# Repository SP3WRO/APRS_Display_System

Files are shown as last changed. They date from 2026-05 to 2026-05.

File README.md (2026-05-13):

# APRS_Display_System
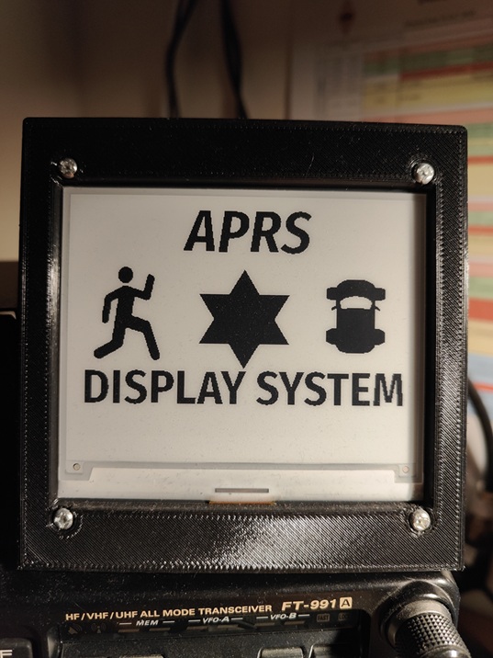
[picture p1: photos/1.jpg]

This is an advanced, multi-functional APRS (Automatic Packet Reporting System) frame display based on the ESP32-WROOM microcontroller. It is used to receive, decode, and display radio (or internet) frames on a low-power e-ink (WeAct 4,2'' BW) screen.

## Programming Description
* The SP3WRO_APRS_DISPLAY.ino and icons.h files should be located together in one folder.
Run the .ino file in the Arduino IDE. In the tools menu, select the HUGE APP (3MB No OTA/1MB SPIFFS) option, as shown in the image.
Then compile the program and upload it to the device. After a moment, the welcome screen will launch.
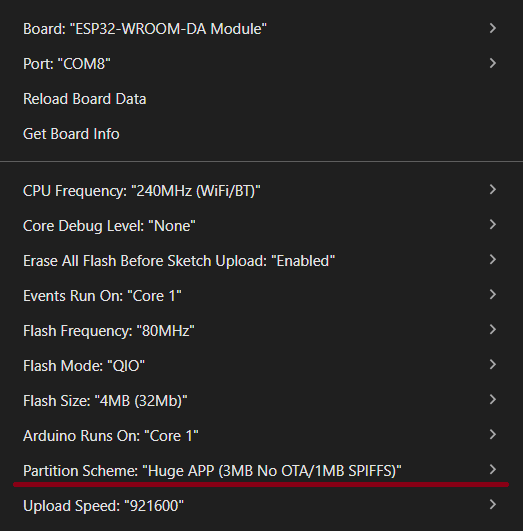
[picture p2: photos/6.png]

## **Four Operating Modes (Data Interfaces):**

- VP-Digi UART (Hardware TNC): The program receives data directly via the physical RX/TX pins from an external modem (e.g., VP-Digi) using the KISS protocol.

* KISS TCP: The ESP32 connects via Wi-Fi as a client to an external KISS TCP server (e.g., DireWolf running on a Raspberry Pi).
* APRS-IS: The ESP32 connects to the global APRS-IS network (e.g., poland.aprs2.net) via WiFi, authenticates with your username and password (passcode), and collects traffic from the surrounding area.
* Bluetooth SPP (HC-05 Client): The ESP32 uses its built-in Bluetooth module to wirelessly connect to an external modem equipped with an HC-05 module (e.g., a mobile tracker or radio).

## **Mechanisms:**
* BT Auto-Fallback (Failover Access Point): If the ESP32 fails to connect to the HC-05 module three times in a row in Bluetooth mode (e.g., radio off, power failure), the program automatically stops attempts, safely resets, and starts its own WiFi network (AP: APRS_DISPLAY_SETUP, IP: 192.168.4.1). This ensures you never lose access to the configuration panel in the event of a modem failure.

## **Data Decoding and Processing (Parser):**
* The program has a powerful internal decoder. It can parse the pure AX.25 protocol wrapped in KISS frames.

## **Supported Formats:**

* Standard position frames, compressed Mic-E format, Base91, weather (WX), and station information (PHG).

## **Radio Identification:**

* The system can recognize the radio model from which the packet was sent (e.g., Yaesu FTM-400, FTM-300, Kenwood TH-D74, APRSdroid app, etc.) based on the comment or destination callsign (TOCALL).

## **Navigational Mathematics:**

* The program continuously calculates the distance (in kilometers) and azimuth (direction, e.g., NW, SE) from your fixed location to the received object.

## **Screen Logic and Display (E-Ink 4.2"):**
* **Classic Mode:**
Displays a large icon of the last received station, an icon (e.g., car, stick figure, home station), a compass rose indicating the direction to the station, raw/decoded data, and the two previous stations in the history.
* **List Mode:**
A more compact layout that displays up to 6 recent stations one below the other, along with a shortened distance, direction, and radio model.
* **EMCOM:** Packets with the EMERGENCY flag bypass filters, activate a visual alarm at the bottom of the screen, trigger an immediate display refresh, and prevent the message from disappearing for one minute.

## **Filters and Additional Features:**
* **Anti-Duplicate:** The program ignores identical packets from the same station for 10 seconds (rejects retransmissions from Digipeaters).
* **Distance Filter:** Ability to reject stations located further than a specified distance.
* **Built-in Web Server:** A complete graphical interface accessible via a browser. It allows you to change all options, enter passwords, change the display mode, and includes a live view of the "Terminal," which receives raw data and device logs.
* **Beacon:** Option to automatically send your own position (frame) to the air (via UART/BT/TCP) or to the network (APRS-IS) at specified intervals.
* **Icons:** The device recognizes the most commonly used icons and displays them in the upper right corner of the screen.

## **Hardware Connection Diagram (Pinout)**
The E-Ink screen uses an SPI bus, while the TNC requires a hardware serial port (UART2). Below is a detailed table showing how to connect the cables between the modules and the ESP32 board (WROOM-32 / DevKit) and an E-Ink display (e.g., Waveshare / GxEPD2 4.2"). Note that the ESP32 has hardware pins assigned for SPI (SCK and MOSI), and the remaining control pins are defined manually in the code.
||||
|--|--|--|
**Pin on E-Ink module** | **Pin on ESP32** | **Description (Function)** |
|VCC | 3.3V | Power supply for the display logic (Never 5V!)|
|GND | GND | Common ground|
|SDA | GPIO 23 | Sending data from ESP to the display (Hardware SPI)|
|SCL | GPIO 18 | Bus clock (Hardware SPI)|
|CS  | GPIO 5 | Defined in code as EPD_CS|
|DC | GPIO 17 | Defined in code as EPD_DC|
|RES | GPIO 16 | Defined in code as EPD_RST|
|BUSY | GPIO 4 | Defined in code as EPD_BUSY|

## Hardware Modem (VP-Digi / TNC) ↔ ESP32 (UART Mode)
The connection uses the hardware serial port on the ESP32. It requires a crossover connection (TX to RX).

||||
|--|--|--|
**Modem pin (e.g., VP-Digi)** | **ESP32 pin** |**Description (Function)**
TX (Transmit from TNC) | GPIO 26 | Defined as VP_RX_PIN (ESP32 receives data)
RX (Receive on TNC) | GPIO 27 | Defined as VP_TX_PIN (ESP32 sends beacon)
GND (Ground) | GND | Common ground between the chips is absolutely critical!

## **Bluetooth module (HC-05 connected to radio)**
* You connect the HC-05 to your mobile modem/radio via hardware using RX/TX cables (e.g., to the DATA port). * The ESP32 board communicates fully wirelessly with this HC-05 via Bluetooth and the MAC address entered in the web configuration panel.
* **Note: WiFi is disabled when using Bluetooth mode!**
## Info
* Software: Mateusz SP3WRO czysty61@gmail.com
* Case: Patryk patrykst1999@o2.pl

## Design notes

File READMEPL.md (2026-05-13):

# APRS_Display_System
Welcome display
To zaawansowany, wielofunkcyjny wyświetlacz ramek APRS (Automatic Packet Reporting System) oparty na mikrokontrolerze ESP32-WROOM, który służy do odbierania, dekodowania i wyświetlania ramek radiowych (lub internetowych) na energooszczędnym ekranie e-ink (WeAct 4,2" BW).

## Opis programowania
Pliki SP3WRO_APRS_DISPLAY.ino oraz icons.h powinny znajdować się razem w jednym folderze.
Uruchamiamy plik .ino w Arduino IDE. W narzędziach wybieramy opcję HUGE APP (3MB No OTA/1MB SPIFFS) tak jak na zdjęciu.
Następnie kompilujemy program i wgrywamy na urządzenie. Po chwili uruchomi się ekran powitalny.
Welcome display
## **Cztery tryby pracy (Złącza danych):**

- VP-Digi UART (Sprzętowy TNC): Program odbiera dane bezpośrednio przez fizyczne piny RX/TX z zewnętrznego modemu (np. VP-Digi) używając protokołu KISS.

* KISS TCP: ESP32 łączy się przez WiFi jako klient z zewnętrznym serwerem KISS TCP (np. z programem DireWolf działającym na Raspberry Pi).
* APRS-IS: ESP32 łączy się przez internet za pomocą WiFi z globalną siecią APRS-IS (np. poland.aprs2.net), autoryzuje się Twoim znakiem i hasłem (passcode) i pobiera ruch z okolicy.
* Bluetooth SPP (Klient HC-05): ESP32 wykorzystuje swój wbudowany moduł Bluetooth, aby bezprzewodowo połączyć się z zewnętrznym modemem wyposażonym w moduł HC-05 (np. z mobilnym trackerem czy radiem).

## **Mechanizmy:**
* BT Auto-Fallback (Awaryjny Punkt Dostępu): Jeśli ESP32 w trybie Bluetooth nie zdoła połączyć się z modułem HC-05 trzy razy z rzędu (np. wyłączone radio, awaria zasilania), program automatycznie wstrzymuje próby, resetuje się w bezpieczny sposób i uruchamia własną sieć WiFi (AP: APRS_DISPLAY_SETUP, IP: 192.168.4.1). Dzięki temu nigdy nie tracisz dostępu do panelu konfiguracyjnego w razie awarii modemu.

## **Dekodowanie i Przetwarzanie Danych (Parser):**
* Program posiada potężny wewnętrzny dekoder. Potrafi analizować czysty protokół AX.25 zawinięty w ramki KISS.
  
## **Obsługiwane formaty:** 

* Standardowe ramki pozycyjne, format skompresowany Mic-E, Base91, pogodowe (WX) oraz informacje o stacji (PHG).
  
## **Identyfikacja Radia:**
  
* System potrafi rozpoznać, z jakiego modelu radia został wysłany pakiet (np. Yaesu FTM-400, FTM-300, Kenwood TH-D74, aplikacja APRSdroid itp.) na podstawie komentarza lub znaków docelowych (TOCALL).

## **Matematyka nawigacyjna:**

* Program na bieżąco oblicza dystans (w kilometrach) oraz azymut (kierunek, np. NW, SE) z Twojej stałej lokalizacji do odebranego obiektu.

## **Logika Ekranu i Wyświetlanie (E-Ink 4.2"):**
* **Tryb Klasyczny:** 
Wyświetla duży znak ostatnio odebranej stacji, ikonę (np. samochód, ludzik, stacja domowa), różę wiatrów wskazującą kierunek do stacji, surowe/zdekodowane dane oraz dwie poprzednie stacje w historii.
* **Tryb Listy:** 
Bardziej kompaktowy układ wyświetlający do 6 ostatnich stacji jedna pod drugą, wraz ze skróconym dystansem, kierunkiem i modelem radia.
* **EMCOM:** Pakiety z flagą EMERGENCY omijają filtry, aktywują wizualny alarm na dole ekranu, wyzwalają natychmiastowe odświeżenie wyświetlacza i blokują zniknięcie komunikatu przez minutę.

## **Filtry i Funkcje Dodatkowe:** 
* **Anti-Duplicate:** Program ignoruje identyczne pakiety z tej samej stacji przez 10 sekund (odrzuca retransmisje z digipeaterów).
* **Filtr Dystansu:** Możliwość odrzucenia stacji znajdujących się dalej niż zadany limit kilometrów.
* **Wbudowany Serwer WWW:** Kompletny interfejs graficzny dostępny z poziomu przeglądarki. Umożliwia zmianę wszystkich opcji, wpisywanie haseł, zmianę trybu wyświetlania i zawiera podgląd na żywo tzw. "Terminala", na który spływają surowe dane i logi pracy urządzenia.
* **Beacon:** Opcja automatycznego wysyłania własnej pozycji (ramki) w eter (przez UART/BT/TCP) lub do sieci (APRS-IS) w określonym interwale czasu.
* **Ikony:** Urządzenie rozpoznaje większość najczęściej używanych ikon i wyświetla je w prawym górnym rogu ekranu.

## **Schemat połączeń sprzętowych (Pinout)**
Ekran E-Ink wykorzystuje magistralę SPI, natomiast TNC wymaga sprzętowego portu szeregowego (UART2). Poniżej znajduje się dokładna tabela, jak należy połączyć przewody między modułami a płytką ESP32 (WROOM-32 / DevKit) i wyświetlaczem E-Ink (np. Waveshare / GxEPD2 4.2") Zwróć uwagę na to, że układ ESP32 ma przypisane sprzętowe piny dla SPI (SCK i MOSI), a pozostałe piny sterujące zdefiniowane są ręcznie w kodzie.
||||
|--|--|--|
**Pin na module E-Ink** | **Pin na ESP32** | **Opis (Funkcja)** |
|VCC   | 3.3V         | Zasilanie układu logiki ekranu (Nigdy 5V!)|
|GND       | GND      | Wspólna masa|
|SDA  | GPIO 23       | Przesyłanie danych z ESP do ekranu (Hardware SPI)|
|SCL           | GPIO 18      | Zegar taktujący magistrali (Hardware SPI)|
|CS     | GPIO 5       | Zdefiniowany w kodzie jako EPD_CS|
|DC    | GPIO 17      | Zdefiniowany w kodzie jako EPD_DC|
|RST          | GPIO 16      | Zdefiniowany w kodzie jako EPD_RST|
|BUSY    | GPIO 4       | Zdefiniowany w kodzie jako EPD_BUSY|

## Sprzętowy Modem (VP-Digi / TNC) ↔ ESP32 (Tryb UART)
Połączenie wykorzystuje sprzętowy port Serial na ESP32. Wymaga połączenia na krzyż (TX do RX).
||||
|--|--|--|
**Pin z modemu (np. VP-Digi)**   |   **Pin na ESP32**    |**Opis (Funkcja)**
TX (Nadawanie z TNC)         |     GPIO 26  |   Zdefiniowany jako VP_RX_PIN (ESP32 odbiera dane)
RX (Odbieranie w TNC)        |     GPIO 27   |  Zdefiniowany jako VP_TX_PIN (ESP32 wysyła beacona)
GND (Masa)                   |       GND      | Wspólna masa między układami jest absolutnie krytyczna!

## **Moduł Bluetooth (HC-05 podłączony do radia)**
* HC-05 podłączasz sprzętowo za pomocą przewodów RX/TX do swojego modemu mobilnego/radia (np. do portu DATA).
* Płytka ESP32 komunikuje się z tym HC-05 w pełni bezprzewodowo z Bluetooth i adresu MAC wpisanego w panelu konfiguracyjnym WWW.
* **Uwaga! W trakcie używania trybu Bluetooth wyłączone jest WiFi!**

## Info
* Software: Mateusz SP3WRO czysty61@gmail.com
* Case: Patryk patrykst1999@o2.pl

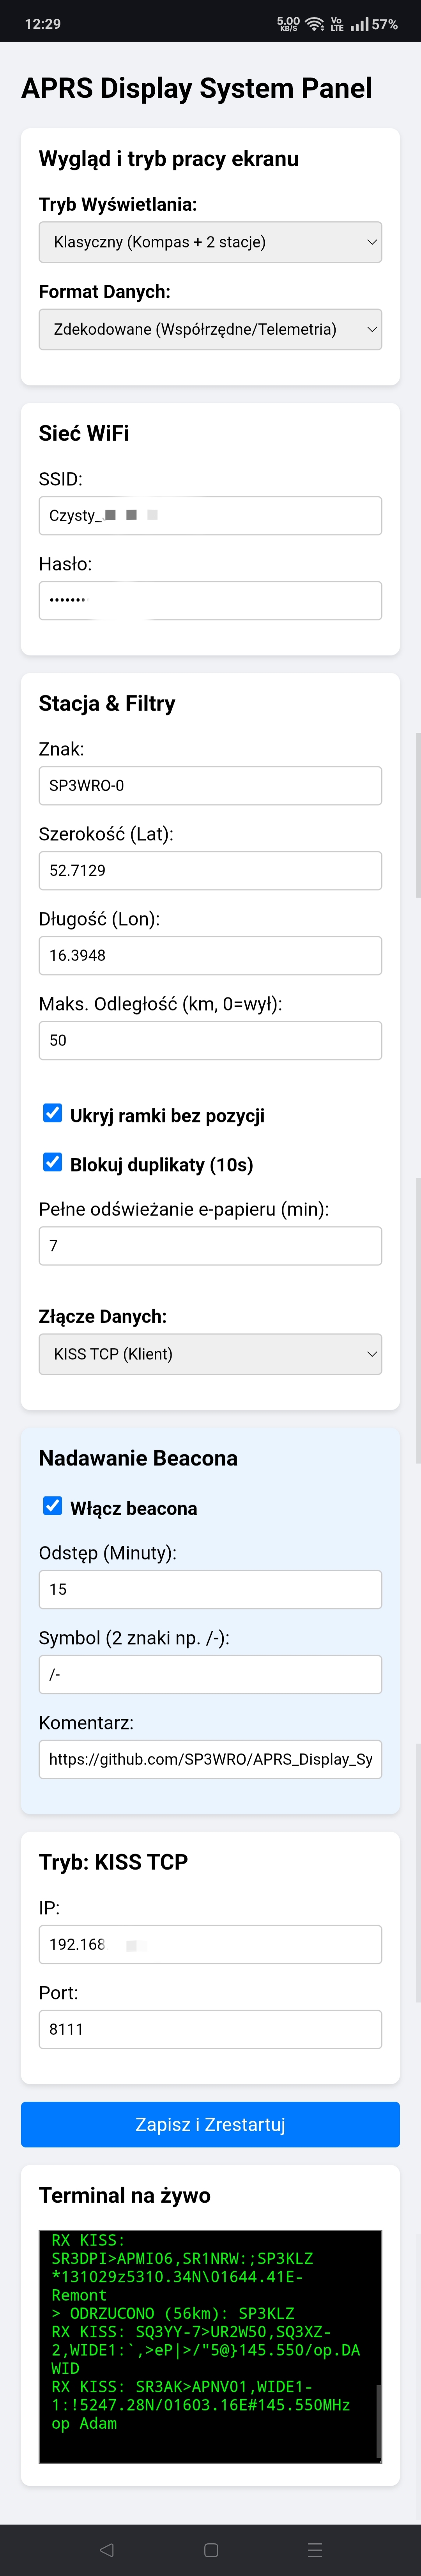
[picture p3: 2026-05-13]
photos/webpanel.jpg

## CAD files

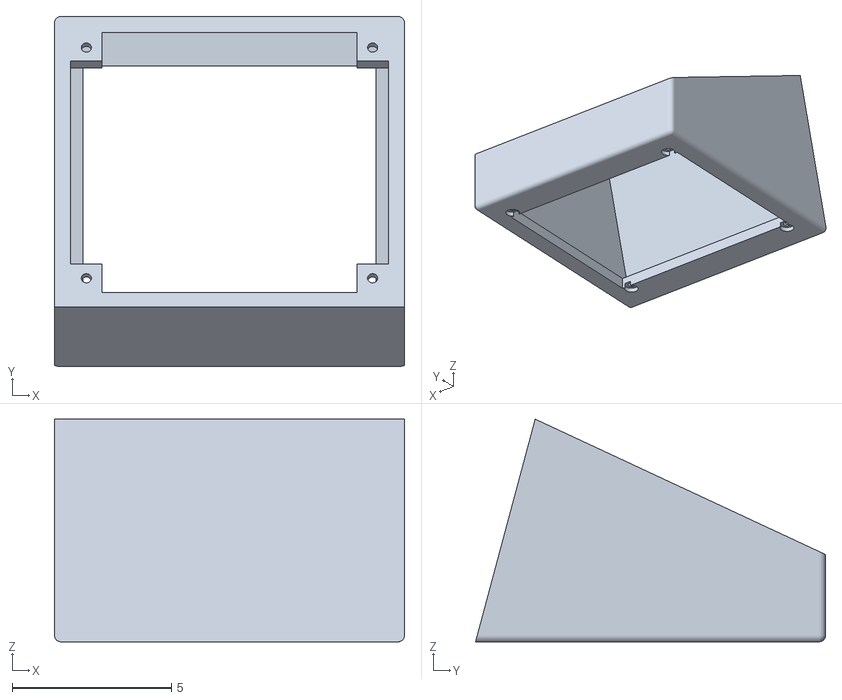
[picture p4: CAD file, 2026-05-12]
case/1.stl
11.0 x 11.0 x 7.00

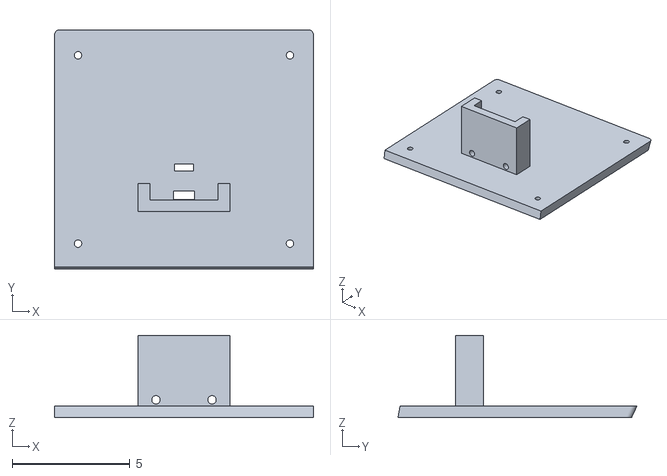
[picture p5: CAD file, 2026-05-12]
case/2.stl
11.0 x 10.2 x 3.50

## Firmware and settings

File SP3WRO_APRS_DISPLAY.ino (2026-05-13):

#include <Arduino.h>
#include <WiFi.h>
#include <WebServer.h>
#include <Preferences.h>
#include <WiFiClient.h>
#include "BluetoothSerial.h"
#include "icons.h"
#include <math.h>

// --- KONFIGURACJA EKRANU ---
#define ENABLE_GxEPD2_GFX 0
#include <GxEPD2_BW.h>
#include <Fonts/FreeMonoBold9pt7b.h>
#include <Fonts/FreeSansBold18pt7b.h>
#include <Fonts/FreeSansBold12pt7b.h>
#include <Fonts/FreeSans9pt7b.h>

#define EPD_CS 5
#define EPD_DC 17
#define EPD_RST 16
#define EPD_BUSY 4
GxEPD2_BW<GxEPD2_420_GDEY042T81, GxEPD2_420_GDEY042T81::HEIGHT> display(GxEPD2_420_GDEY042T81(EPD_CS, EPD_DC, EPD_RST, EPD_BUSY));

// --- KONFIGURACJA UART ---
#define VP_RX_PIN 26 
#define VP_TX_PIN 27 
HardwareSerial VPSerial(2); 

// --- SERWER, KLIENT, BT ---
WebServer server(80);
Preferences prefs;
WiFiClient tcpClient; 
BluetoothSerial SerialBT;

enum AppMode { MODE_KISS_UART, MODE_KISS_TCP, MODE_APRS_IS, MODE_KISS_BT };

struct Config {
  String callsign = "N0CALL";
  int currentMode = MODE_KISS_UART;
  int displayMode = 0; 
  int dataFormat = 0; 
  float myLat = 52.1234;
  float myLon = 16.1234;
  int maxDistKm = 50;
  
  int uartBaud = 9600; 
  
  String kissIP = "192.168.1.100";
  int kissPort = 8001;
  String isServer = "poland.aprs2.net";
  int isPort = 14580;
  String isCall = "N0CALL";
  String isPass = "12345";
  String wifiSSID = "";
  String wifiPass = "";
  
  String btAddress = "00:00:00:00:00:00";
  String btPin = "1234";
  
  bool beaconEnabled = false;
  int beaconInterval = 30;
  String beaconSymbol = "/-"; 
  String beaconComment = "APRS Display System";
  bool hideNonPositional = false;
  bool antiDuplicate = false; 
  int refreshInterval = 60; 
} appConfig;

struct APRSPacket {
  String sourceCall;
  String destCall; 
  String path;
  String payload;
  String rawPacket; 
  String parsedText; 
  String comment; 
  char symbolTable; 
  char symbolCode;
  float distance; 
  float bearing;
  float lat;         
  float lon;
  bool isEmergency = false; 
  bool isWX = false; 
  String radioModel = ""; 
};

const int MAX_HISTORY = 8; 
APRSPacket history[MAX_HISTORY];
APRSPacket lastPacket;

const int MAX_TERM_LINES = 15;
String terminalLines[MAX_TERM_LINES];
int termIndex = 0;

// --- BUFOR ANTYDUPLIKATOWY ---
struct SeenStation {
  String call;
  String payload;
  unsigned long lastSeen;
};
const int MAX_SEEN = 20;
SeenStation seenStations[MAX_SEEN];
int seenIndex = 0;

// --- FLAGI I STOPERY ---
bool forceFullRefresh = true; 
unsigned long lastTcpRetry = 0; 
unsigned long lastRefreshTime = 0; 
unsigned long lastBeaconTime = 0; 
bool isisLoggedIn = false; 
bool newDataToDisplay = false;         
unsigned long lastDisplayUpdate = 0;
unsigned long emergencyUnlockTime = 0; 

// --- BT FALLBACK ---
bool btFallbackTriggered = false;
unsigned long btConnectAttemptTime = 0;
unsigned long lastBtRetry = 0;
int btFailedAttempts = 0;

// --- ZMIENNE PROTOKOŁU KISS ---
#define FEND 0xC0
#define FESC 0xDB
#define TFEND 0xDC
#define TFESC 0xDD
uint8_t kissBuffer[512];
int kissIndex = 0;
bool kissEscaped = false;

// --- TERMINAL LOGGER ---
void addToTerminal(String log) {
  terminalLines[termIndex] = log;
  termIndex = (termIndex + 1) % MAX_TERM_LINES;
  Serial.println(log); 
}

String getTerminalText() {
  String txt = "";
  for(int i = 0; i < MAX_TERM_LINES; i++) {
    int idx = (termIndex + i) % MAX_TERM_LINES;
    if(terminalLines[idx].length() > 0) txt += terminalLines[idx] + "\n";
  }
  return txt;
}

// --- NARZĘDZIA TEKSTOWE ---

String identifyRadio(String tocall) {
  if (tocall.startsWith("APY008")) return "VX-8R";
  if (tocall.startsWith("APY01D")) return "FTM-100D";
  if (tocall.startsWith("APY02D")) return "FTM-200D";
  if (tocall.startsWith("APY03D")) return "FTM-300D";
  if (tocall.startsWith("APY04D")) return "FTM-400D";
  if (tocall.startsWith("APY05D")) return "FTM-500D";
  if (tocall.startsWith("APY1DR")) return "FT1D";
  if (tocall.startsWith("APY2DR")) return "FT2D";
  if (tocall.startsWith("APY3DR")) return "FT3D";
  if (tocall.startsWith("APY5DR")) return "FT5D";

  if (tocall.startsWith("APK003")) return "TH-D7";
  if (tocall.startsWith("APK004")) return "TM-D700";
  if (tocall.startsWith("APK005")) return "TM-D710";
  if (tocall.startsWith("APK006")) return "TH-D72";
  if (tocall.startsWith("APK007")) return "TM-D710G";
  if (tocall.startsWith("APK008")) return "TH-D74";
  if (tocall.startsWith("APK009")) return "TH-D75";

  if (tocall.startsWith("APA878")) return "AT-D878UV";
  if (tocall.startsWith("APA578")) return "AT-D578UV";

  if (tocall.startsWith("APLR")) return "LoRa Tracker";
  if (tocall.startsWith("APLORA")) return "LoRa Tracker";

  if (tocall.startsWith("APL")) return "Alinco";
  if (tocall.startsWith("APOX")) return "PicoAPRS";

  return ""; 
}

String identifyMicERadio(String &comment) {
  while(comment.length() > 0) {
    char c = comment.charAt(comment.length()-1);
    if (c < 32 || c > 126) {
        comment = comment.substring(0, comment.length() - 1);
    } else {
        break;
    }
  }

  if (comment.length() == 0) return "";

  String model = "";

  if (comment.length() >= 2) {
    String last2 = comment.substring(comment.length() - 2);
    
    if (last2 == " X") model = "AP510";
    else if (last2 == "(5") model = "D578UV";
    else if (last2 == "(8") model = "D878UV";
    else if (last2 == "*9") model = "AVRT9";
    else if (last2 == "*v") model = "Tracker (KissOZ)";
    else if (last2 == ":2") model = "VP-Tracker";
    else if (last2 == "[1") model = "APRSdroid";
    else if (last2 == "^v") model = "anyfrog";
    else if (last2 == "_ ") model = "VX-8";
    else if (last2 == "_\"") model = "FTM-350";
    else if (last2 == "_#") model = "VX-8G";
    else if (last2 == "_$") model = "FT1D";
    else if (last2 == "_%") model = "FTM-400DR";
    else if (last2 == "_(") model = "FT2D";
    else if (last2 == "_)") model = "FTM-100D";
    else if (last2 == "_0") model = "FT3D";
    else if (last2 == "_1") model = "FTM-300D";
    else if (last2 == "_2") model = "FTM-200D";
    else if (last2 == "_3") model = "FT5D";
    else if (last2 == "_4") model = "FTM-500D";
    else if (last2 == "_5") model = "FTM-510D";
    else if (last2 == "_6") model = "FTX-1";
    else if (last2 == "_7") model = "FTM-310D";
    else if (last2 == "|3") model = "TinyTrak3";
    else if (last2 == "|4") model = "TinyTrak4";

    if (model != "") {
       comment = comment.substring(0, comment.length() - 2); 
       return model;
    }
  }

  char firstChar = comment.charAt(0);
  char lastChar = comment.charAt(comment.length() - 1);

  if (firstChar == ']') {
      if (lastChar == '=') {
          model = "TM-D710";
          comment = comment.substring(0, comment.length() - 1); 
      } else {
          model = "TM-D700";
      }
      return model;
  } 
  else if (firstChar == '>') {
      if (lastChar == '=') {
          model = "TH-D72";
          comment = comment.substring(0, comment.length() - 1);
      } else if (lastChar == '^') {
          model = "TH-D74";
          comment = comment.substring(0, comment.length() - 1);
      } else if (lastChar == '&') {
          model = "TH-D75";
          comment = comment.substring(0, comment.length() - 1);
      } else {
          model = "TH-D7A";
      }
      return model;
  }

  if (comment.length() >= 2 && comment.charAt(comment.length() - 2) == '_') {
     comment = comment.substring(0, comment.length() - 2);
     return "Yaesu";
  }

  return "";
}

String removePolishChars(String input) {
  String out = input;
  out.replace("ą", "a"); out.replace("Ą", "A");
  out.replace("ć", "c"); out.replace("Ć", "C");
  out.replace("ę", "e"); out.replace("Ę", "E");
  out.replace("ł", "l"); out.replace("Ł", "L");
  out.replace("ń", "n"); out.replace("Ń", "N");
  out.replace("ó", "o"); out.replace("Ó", "O");
  out.replace("ś", "s"); out.replace("Ś", "S");
  out.replace("ź", "z"); out.replace("Ź", "Z");
  out.replace("ż", "z"); out.replace("Ż", "Z");
  return out;
}

void cleanDAO(String &commentText) {
  int daoW = commentText.indexOf("!W");
  if (daoW > 0 && daoW + 4 <= commentText.length() && commentText.charAt(daoW + 3) == '!') {
     commentText = commentText.substring(0, daoW);
  }
  int daow = commentText.indexOf("!w");
  if (daow > 0 && daow + 4 <= commentText.length() && commentText.charAt(daow + 3) == '!') {
     commentText = commentText.substring(0, daow);
  }
  commentText.trim();
}

// --- MATEMATYKA I KIERUNKI ---
float calculateDistance(float lat1, float lon1, float lat2, float lon2) {
  float R = 6371.0; 
  float dLat = (lat2 - lat1) * M_PI / 180.0;
  float dLon = (lon2 - lon1) * M_PI / 180.0;
  lat1 = lat1 * M_PI / 180.0;
  lat2 = lat2 * M_PI / 180.0;
  float a = sin(dLat/2) * sin(dLat/2) + sin(dLon/2) * sin(dLon/2) * cos(lat1) * cos(lat2);
  float c = 2 * atan2(sqrt(a), sqrt(1-a));
  return R * c;
}

float calculateBearing(float lat1, float lon1, float lat2, float lon2) {
  float dLon = (lon2 - lon1) * M_PI / 180.0;
  lat1 = lat1 * M_PI / 180.0;
  lat2 = lat2 * M_PI / 180.0;
  float y = sin(dLon) * cos(lat2);
  float x = cos(lat1) * sin(lat2) - sin(lat1) * cos(lat2) * cos(dLon);
  float brng = atan2(y, x) * 180.0 / M_PI;
  if (brng < 0) brng += 360.0;
  return brng;
}

String getCompassDir(float bearing) {
  if (bearing < 0) return "";
  const char* dirs[] = {"N", "NE", "E", "SE", "S", "SW", "W", "NW", "N"};
  int idx = round(bearing / 45.0);
  if (idx < 0 || idx > 8) return "";
  return dirs[idx];
}

float parseCoord(String coordStr, bool isLat) {
  if (coordStr.length() < 7) return 0.0;
  float degrees = coordStr.substring(0, isLat ? 2 : 3).toFloat();
  float minutes = coordStr.substring(isLat ? 2 : 3, isLat ? 7 : 8).toFloat();
  float decimalDeg = degrees + (minutes / 60.0);
  char dir = coordStr.charAt(coordStr.length() - 1);
  if (dir == 'S' || dir == 'W') decimalDeg = -decimalDeg;
  return decimalDeg;
}

// --- DEKODERY ---
bool isNumericStr(String str) {
  for(int i=0; i<str.length(); i++) {
    if(!isDigit(str.charAt(i)) && str.charAt(i) != ' ' && str.charAt(i) != '-') return false;
  }
  return true;
}

String decodeWeather(String &commentText) {
  String out = "";
  bool hasData = false;
  
  int spaceIdx = commentText.indexOf(' ');
  String wxData = (spaceIdx >= 0) ? commentText.substring(0, spaceIdx) : commentText;
  String restComment = (spaceIdx >= 0) ? commentText.substring(spaceIdx + 1) : "";
  
  String dirStr = "", spdStr = "";
  
  if (wxData.length() >= 7 && wxData.charAt(3) == '/') {
    dirStr = wxData.substring(0, 3);
    spdStr = wxData.substring(4, 7);
  } 
  else if (wxData.indexOf('c') >= 0 && wxData.indexOf('s') >= 0) {
    int cIdx = wxData.indexOf('c');
    int sIdx = wxData.indexOf('s');
    if (cIdx + 3 < wxData.length() && sIdx + 3 < wxData.length()) {
      dirStr = wxData.substring(cIdx + 1, cIdx + 4);
      spdStr = wxData.substring(sIdx + 1, sIdx + 4);
    }
  } 
  else {
    int uscore = wxData.indexOf('_');
    if (uscore >= 0 && uscore + 8 <= wxData.length() && wxData.charAt(uscore + 4) == '/') {
      dirStr = wxData.substring(uscore + 1, uscore + 4);
      spdStr = wxData.substring(uscore + 5, uscore + 8);
    }
  }
  
  auto extractWx = [&](char tag, int len) -> String {
    int idx = wxData.indexOf(tag);
    if (idx >= 0 && idx + len < wxData.length()) {
      String val = wxData.substring(idx + 1, idx + 1 + len);
      if (isNumericStr(val)) return val;
    }
    return "";
  };
  
  String gStr = extractWx('g', 3);
  
  bool hasDir = (dirStr != "" && isNumericStr(dirStr));
  bool hasGust = (gStr != "");
  bool hasSpd = (spdStr != "" && isNumericStr(spdStr));
  
  if (hasGust || hasSpd || hasDir) {
     String windLine = "";
     
     if (hasGust) {
        float gustKmh = gStr.toFloat() * 1.609;
        windLine += "Wmax: " + String(gustKmh, 1) + "km/h";
     } else if (hasSpd) {
        float spdKmh = spdStr.toFloat() * 1.609;
        windLine += "Wiatr: " + String(spdKmh, 1) + "km/h";
     }
     
     if (hasDir) {
        if (windLine.length() > 0) windLine += " ";
        windLine += "" + dirStr + "st";
     }
     
     if (windLine.length() > 0) {
        out += windLine + "\n";
        hasData = true;
     }
  }
  
  String tStr = extractWx('t', 3);
  if (tStr != "") {
    int tempF = tStr.toInt();
    int tempC = round((tempF - 32.0) * 5.0 / 9.0);
    out += "Temp: " + String(tempC) + " C\n";
    hasData = true;
  }
  
  int hIdx = wxData.indexOf('h');
  if (hIdx >= 0 && hIdx + 2 <= wxData.length()) {
    String hStr = wxData.substring(hIdx + 1, hIdx + 3);
    if (isNumericStr(hStr)) {
      int hum = hStr.toInt();
      if (hum == 0) hum = 100;
      out += "Wilgotnosc: " + String(hum) + " %\n";
      hasData = true;
    }
  }
  
  String bStr = extractWx('b', 5);
  if (bStr != "") {
    float press = bStr.toFloat() / 10.0;
    out += "Cisn: " + String(press, 1) + " hPa\n";
    hasData = true;
  }
  
  String rStr = extractWx('r', 3);
  if (rStr != "") {
    float rMm = rStr.toFloat() * 0.254;
    out += "Opad(1h): " + String(rMm, 1) + " mm\n";
    hasData = true;
  }
  
  String pStr = extractWx('p', 3);
  if (pStr != "") {
    float pMm = pStr.toFloat() * 0.254;
    out += "Opad(24h): " + String(pMm, 1) + " mm\n";
    hasData = true;
  }
  
  String PStr = extractWx('P', 3);
  if (PStr != "") {
    float PMm = PStr.toFloat() * 0.254;
    out += "Opad(od 0:00): " + String(PMm, 1) + " mm\n";
    hasData = true;
  }
  
  if (!hasData) return "";
  
  out.trim();
  commentText = restComment; 
  return out;
}

String decodePHG(String payload) {
  int phgIdx = payload.indexOf("PHG");
  if (phgIdx >= 0 && phgIdx + 7 <= payload.length()) {
    String phgData = payload.substring(phgIdx + 3, phgIdx + 7);
    bool valid = true;
    for(int i = 0; i < 4; i++) {
      if(!isDigit(phgData.charAt(i))) valid = false;
    }
    if (valid) {
      int p = phgData.charAt(0) - '0';
      int h = phgData.charAt(1) - '0';
      int g = phgData.charAt(2) - '0';
      int d = phgData.charAt(3) - '0';

      int power = p * p;
      int heightM = round(10.0 * pow(2, h) * 0.3048);
      String dir = (d == 0) ? "Omni" : String(d * 45) + "st";

      return "[Radio] " + String(power) + "W, Ant: " + String(heightM) + "m, " + String(g) + "dB, " + dir;
    }
  }
  return "";
}

bool decodeMicE(String dest, String info, float &lat, float &lon, char &symTable, char &symCode, int &speed, int &course, String &statusMsg) {
  String dest6 = dest;
  int dashIdx = dest6.indexOf('-');
  if (dashIdx > 0) dest6 = dest6.substring(0, dashIdx);
  while(dest6.length() < 6) dest6 += " ";

  if (info.length() < 9) return false; 

  int a = 0, b = 0, c = 0;
  bool isCustom = false;
  auto checkMsg = [&](char ch, int &bit) {
    if (ch >= 'A' && ch <= 'K') { bit = 1; isCustom = true; }
    else if (ch >= 'P' && ch <= 'Z') { bit = 1; }
    else { bit = 0; }
  };
  checkMsg(dest6.charAt(0), a);
  checkMsg(dest6.charAt(1), b);
  checkMsg(dest6.charAt(2), c);
  
  int msgId = (a << 2) | (b << 1) | c;
  if (msgId == 0) statusMsg = "Emergency!";
  else if (msgId == 1) statusMsg = isCustom ? "Custom-6" : "Priority";
  else if (msgId == 2) statusMsg = isCustom ? "Custom-5" : "Special"; 
  else if (msgId == 3) statusMsg = isCustom ? "Custom-4" : "Committed";
  else if (msgId == 4) statusMsg = isCustom ? "Custom-3" : "Returning";
  else if (msgId == 5) statusMsg = isCustom ? "Custom-2" : "In Service";
  else if (msgId == 6) statusMsg = isCustom ? "Custom-1" : "En Route";
  else if (msgId == 7) statusMsg = isCustom ? "Custom-0" : "Off Duty";

  int dLat[6];
  int n = 0, s = 0, w = 0, e = 0, latOff = 0; 

  for(int i=0; i<6; i++) {
    char ch = dest6.charAt(i);
    if(ch >= '0' && ch <= '9') dLat[i] = ch - '0';
    else if(ch >= 'A' && ch <= 'J') dLat[i] = ch - 'A';
    else if(ch >= 'P' && ch <= 'Y') dLat[i] = ch - 'P';
    else if(ch == 'K' || ch == 'L' || ch == 'Z') dLat[i] = 0;
    else return false; 
  }

  char c3 = dest6.charAt(3);
  if(c3 >= 'P' && c3 <= 'Z') n = 1; else s = 1;

  char c4 = dest6.charAt(4);
  if(c4 >= 'P' && c4 <= 'Z') w = 1; else e = 1;

  char c5 = dest6.charAt(5);
  if(c5 >= 'P' && c5 <= 'Z') latOff = 100;

  lat = (dLat[0]*10 + dLat[1]) + (dLat[2]*10 + dLat[3])/60.0 + (dLat[4]*10 + dLat[5])/6000.0;
  if (s) lat = -lat;

  int dLon = info.charAt(1) - 28;
  if(latOff) dLon += 100;
  if(dLon >= 180 && dLon <= 189) dLon -= 80;
  else if(dLon >= 190 && dLon <= 199) dLon -= 190;

  int mLon = info.charAt(2) - 28;
  if(mLon >= 60) mLon -= 60;

  int hLon = info.charAt(3) - 28;
  lon = dLon + mLon/60.0 + hLon/6000.0;
  if (w) lon = -lon;

  speed = 0; course = 0;
  int spdByte = info.charAt(4) - 28;
  int crsByte1 = info.charAt(5) - 28;
  int crsByte2 = info.charAt(6) - 28;
  if (spdByte >= 0 && crsByte1 >= 0 && crsByte2 >= 0) {
      speed = (spdByte * 10) + (crsByte1 / 10);
      if (speed >= 800) speed -= 800; 
      course = ((crsByte1 % 10) * 100) + crsByte2;
      if (course >= 400) course -= 400; 
  }

  symCode = info.charAt(7);
  symTable = info.charAt(8);

  return true;
}

bool decodeBase91(String payload, float &lat, float &lon, char &symTable, char &symCode, int &commentOffset) {
  int compStart = -1;

  for (int i = 0; i < payload.length() - 13; i++) {
    char c = payload.charAt(i);
    if (c == '!' || c == '=') {
      compStart = i + 1;
      break;
    }
    else if (c == '/' || c == '@') {
      if (i + 8 + 9 <= payload.length()) { 
        compStart = i + 8;
        break;
      }
    }
  }

  if (compStart >= 0 && compStart + 10 <= payload.length()) {
    bool valid = true;
    for(int j = compStart + 1; j < compStart + 9; j++) {
       char b = payload.charAt(j);
       if (b < 33 || b > 124) { valid = false; break; }
    }

    if (valid) {
      symTable = payload.charAt(compStart);
      symCode = payload.charAt(compStart + 9);

      long y = 0;
      y += (long)(payload.charAt(compStart + 1) - 33) * 753571;
      y += (long)(payload.charAt(compStart + 2) - 33) * 8281;
      y += (long)(payload.charAt(compStart + 3) - 33) * 91;
      y += (long)(payload.charAt(compStart + 4) - 33);
      lat = 90.0 - ((float)y / 380926.0);

      long x = 0;
      x += (long)(payload.charAt(compStart + 5) - 33) * 753571;
      x += (long)(payload.charAt(compStart + 6) - 33) * 8281;
      x += (long)(payload.charAt(compStart + 7) - 33) * 91;
      x += (long)(payload.charAt(compStart + 8) - 33);
      lon = -180.0 + ((float)x / 190463.0);

      commentOffset = compStart + 12;
      if (payload.length() > commentOffset) {
          if (payload.charAt(commentOffset) != ' ') {
              commentOffset++; 
          }
      }
      return true;
    }
  }
  return false;
}

const unsigned char* getSymbolBitmap(char table, char code) {
  if (table == 'L' && (code == '#' || code == '&' || code == 'a' || code == '_')) return icon_lora; 
  if (code == '#') return icon_digi; 
  if (table == '/') {
    switch (code) {
      case 'V': return icon_v;    
      case '>': case 'F': case 'P': case 'R': case 'U': 
      case 'a': case 'f': case 'j': case 'k': case 'u': case 'v':
        return icon_car;           
      case '_': return icon_wx;            
      case '[': return icon_handheld;      
      case '-': return icon_home;          
      case ';': return icon_campground;    
      case 'O': return icon_balloon;       
      case 'r': return icon_repeater;      
      case 'S': return icon_shuttle;       
      case '<': return icon_motorcycle;    
      case 'L': return icon_lighthouse;    
    }
  } else if (table == '\\') {
    switch (code) {
      case 'u': case 'v': case 'k':
        return icon_car;
      case '-': return icon_home;          
      case ';': return icon_campground;    
      case '<': return icon_motorcycle;    
    }
  }
  return icon_lighthouse;
}

// --- LOGIKA NADAWANIA ---
void addCallsignToAX25(uint8_t* frame, int& len, String call, int defaultSsid, bool isLast) {
  int ssid = defaultSsid;
  int dashIdx = call.indexOf('-');
  if (dashIdx > 0) {
    ssid = call.substring(dashIdx + 1).toInt();
    call = call.substring(0, dashIdx);
  }
  call.toUpperCase();
  while (call.length() < 6) call += " "; 
  for (int i = 0; i < 6; i++) {
    frame[len++] = call.charAt(i) << 1; 
  }
  uint8_t ssidByte = 0x60 | ((ssid & 0x0F) << 1);
  if (isLast) ssidByte |= 0x01; 
  frame[len++] = ssidByte;
}
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
void loop() {
  if (appConfig.currentMode != MODE_KISS_BT || btFallbackTriggered) {
      server.handleClient();
  }
  
  handleNetwork();
  
  unsigned long currentMillis = millis();
  
  if (newDataToDisplay && (currentMillis - lastDisplayUpdate >= 3000)) {
    lastDisplayUpdate = currentMillis;
    newDataToDisplay = false;
    updateDisplay();
  }

  if (appConfig.refreshInterval > 0 && (currentMillis - lastRefreshTime >= (appConfig.refreshInterval * 60000UL))) {
    lastRefreshTime = currentMillis;
    forceFullRefresh = true;
    newDataToDisplay = true; 
    addToTerminal("> Automatyczne odświeżenie E-INK");
  }

  if (appConfig.beaconEnabled && appConfig.beaconInterval > 0) {
    if (currentMillis - lastBeaconTime >= (appConfig.beaconInterval * 60000UL)) {
      lastBeaconTime = currentMillis;
      transmitBeacon();
    }
  }

  if (appConfig.currentMode == MODE_KISS_UART) {
    while (VPSerial.available()) {
      uint8_t b = VPSerial.read();
      parseKISS(b); 
    }
  }

  // ZABEZPIECZENIE: Używaj SerialBT tylko jeśli nie działa tryb awaryjny
  if (appConfig.currentMode == MODE_KISS_BT && !btFallbackTriggered && SerialBT.connected()) {
    int maxReads = 128;
    while (SerialBT.available() && maxReads-- > 0) {
      uint8_t b = SerialBT.read();
      parseKISS(b);
    }
  }

  delay(10); 
}
